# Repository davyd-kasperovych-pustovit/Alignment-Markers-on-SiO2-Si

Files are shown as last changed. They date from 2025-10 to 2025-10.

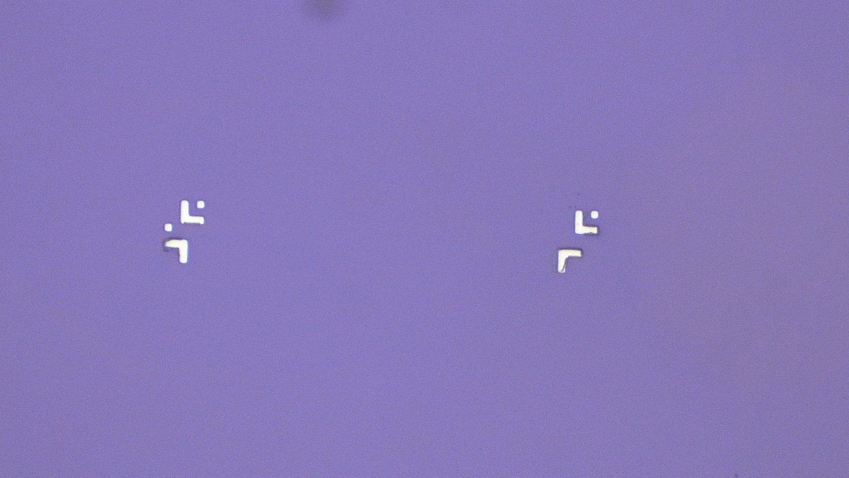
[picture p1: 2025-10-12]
Lift Off Testing/Without Ultrasonic/Lift Off - 2.jpg

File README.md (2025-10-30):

**Alignment Marker Fabrication Process**

**Author:** Davyd Kasperovych-Pustovit

**Affiliation:** Quantum Materials and Devices Lab, Duke University

**Overview**

This repository documents the development and standardization of a photolithography-based alignment marker fabrication process used for device registration and sample alignment in the Quantum Materials and Devices Lab at Duke University.

The project focuses on optimizing process steps to achieve high-fidelity Cr/Au alignment markers on SiO₂/Si substrates with micron-level precision. Through workflow redesign and parameter optimization, total fabrication time was reduced from 12 to 6 hours per 80 markers, while maintaining sub-2 µm feature resolution and consistent pattern reproducibility.

This process is now adopted as the lab’s standard protocol for marker-chip fabrication and serves as the foundation for subsequent device fabrication steps, including graphene and hBN stacking and superconducting device fabrication.

For the final results, see Batches/Batch 4.

**Fabrication Summary**

Substrate: SiO₂/Si wafers (285 nm oxide layer)
Metallization: Cr/Au (5 nm / 50 nm) via thermal evaporation
Resolution: ≤ 2 µm

**Author Notes**

This repository is part of my ongoing undergraduate research in the Quantum Materials and Devices Lab at Duke University.
For questions, collaboration, or feedback, please contact me at:
📧 davydkasperovych@gmail.com

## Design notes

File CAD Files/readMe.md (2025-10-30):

CAD files were adopted from Chun-Chia Chen, Ph.D, and modified by me.
Main change was in the rotation of the left-top marker such that the relative direction can be identified.

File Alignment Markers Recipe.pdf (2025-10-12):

# Procedure for Producing Alignment Markers

# on SiO2/Si Wafers Using Photolithography

Duke University

Quantum Materials and Devices Lab

SMIF Cleanroom Protocol

Prepared by Davyd Kasperovych-Pustovit

Revision 3 - July 30, 2025

## Contents

1 Cleaning the Wafer | 2
2 Spin Coating | 2
3 Photolithography | 3
4 Developing | 3
5 EB Evaporation | 3
6 Photoresist Removal | 4
7 Expected Quality of Alignment Markers | 4
8 Optional: Post Sealing | 5

Revision 3

Davyd Kasperovych-Pustovit

## 1 Cleaning the Wafer

1. At the spin coat hood in the yellow room, turn on two hotplates. Set one to 115°C and the other to 135°C. They will be used later.
2. At the solvent hood with ultrasonic machine, prepare:
(a) Acetone
(b) IPA
(c) DI water
(d) Ensure access to hydrogen gas.
3. Set the ultrasonic machine knob to position 5. If the bath is empty, fill it with IPA.
4. Submerge the wafer in a glass dish filled with acetone.
5. Place the dish with the wafer into the ultrasonic machine. Start the cleaning cycle and run for 5 minutes.
6. While cleaning, prepare a second dish with fresh IPA.
7. After 5 minutes, remove the dish. Lift the wafer while rinsing with IPA, and immediately transfer it to the second dish. Do not let the wafer dry—dried acetone causes stains.
8. Gently agitate the second dish for 60 s.
9. Rinse the wafer under running DI water for 20 s.
10. Dry the wafer thoroughly with nitrogen gas.
11. Transfer wafer to the yellow room for prebaking.
12. Bake the wafer on the 135°C hotplate for 3 minutes. Then let it rest on a clean surface for 2 minutes.

## 2 Spin Coating

1. Set the spin coater program to:
(a) Recipe 0
(b) Step 1: 500 rpm, 5 s – spread
(c) Step 2: 4000 rpm, 30 s – achieve 0.5 µm thickness
(d) Step 3: 0 rpm, 0 s – end
2. Place the wafer on the chuck. Turn on the vacuum and ensure the wafer is secure (change chuck if needed).
3. Using a pipette, dispense enough P20 Primer to evenly coat the wafer.
4. Start the spin cycle. Once complete, turn off the vacuum and transfer the wafer to the 115°C hotplate. Bake for 60 s.
5. Let the wafer cool for 60 s.
6. Repeat the coating steps 2-5 using S1805 PR instead of primer.

## 3 Photolithography

1. Place the wafer at the center of Photo3.
2. Set the wafer thickness to 600 µm.
3. Align the wafer precisely in the x and y directions.
4. Define the dimensions of the write area.
5. Use the build job list function to generate a marker grid.
6. Set the exposure parameters:
(a) Mode: Normal
(b) Resolution: 0.6 µm
(c) Intensity: 60 mJ/cm²
7. Start the exposure process and wait for completion.

Note:
1. The resolution must be finer than your smallest feature (e.g., use 0.6 µm for a 1 µm feature).
2. Refer to the official documentation for detailed instructions.

## 4 Developing

1. Submerge the wafer in MF319 developer for 30 s.
2. Rinse immediately under DI water for 30 s.
3. Dry the wafer using pressurized nitrogen.
4. Inspect the developed features under the microscope using green light. Only use microscope inside the yellow room.
5. If features are unclear, extend development time in MF319 or adjust the exposure intensity on Photo3.

## 5 EB Evaporation

1. Deposit metals in the following order: first Cr, then Au.
2. Use the following target thicknesses:
(a) Cr: 5 nm (0.05 k˚A)
(b) Au: 50 nm (0.5 k˚A)
3. Follow all procedures outlined in the EVAP 2 manual.
4. The full process takes approximately 2.5 hours.

## 6 Photoresist Removal

1. Pour 1165 PR remover into a clean glass dish.
2. Submerge the wafer and soak for 8 hours.
IMPORTANT: After this step, the wafer must remain fully submerged in a solution at all times!
3. After soaking, move the dish to the solvent hood with the ultrasonic machine.
4. Set the ultrasonic machine knob to position 2. Note, higher settings increase the risk of small features detaching.
5. Place the dish with the wafer into the machine and run the cleaning cycle for 3 minutes.
6. While cleaning, prepare a second dish with fresh IPA.
7. After 3 minutes, remove the dish. While rinsing the wafer with IPA, carefully lift it and immediately transfer it to a clean dish.
8. Inspect the wafer under a stereo microscope, checking for any remaining gold dust on the surface.
9. If gold dust is still present, repeat the rinse with IPA and transfer the wafer to a new clean dish. Continue until the wafer is completely free of gold dust.
10. Rinse wafer with DI water.
11. Dry the wafer using pressurized nitrogen.
12. Inspect the wafer to ensure complete photoresist removal.

## 7 Expected Quality of Alignment Markers

1. After Step 4 - Developing in MF319

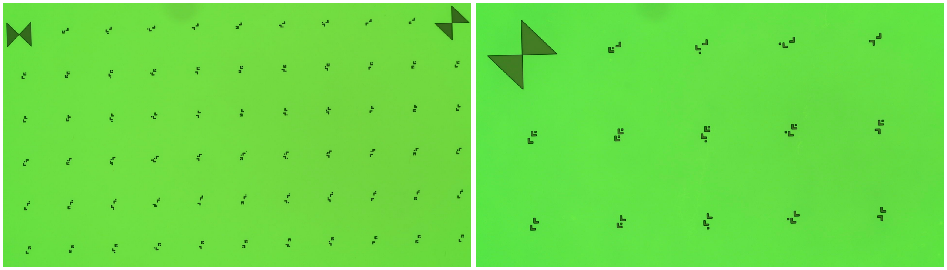
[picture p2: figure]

2. After Step 6 - Photoresist Removal

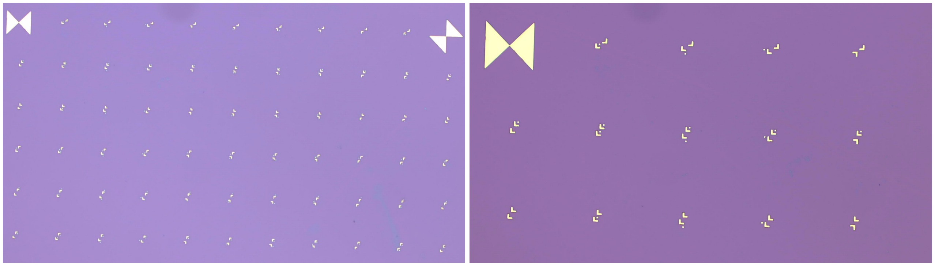
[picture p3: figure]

## 8 Optional: Post Sealing

After complete removal of photoresist (PR), the next step may involve dicing the wafer. This process poses a risk of contaminating wafer features with dust and other particles. To protect the surface, the wafer is coated with a temporary layer of resist that serves as a protective seal.

This layer prevents particle adhesion and can be easily removed after dicing using the standard PR removal procedure.

The procedure is outlined below.
1. At the spin coat hood in the yellow room, set up a hotplate to 180°C. It will be used later.
2. At the solvent hood with ultrasonic machine, prepare:
(a) Acetone
(b) IPA
(c) DI water
(d) Ensure access to hydrogen gas.
3. Set the ultrasonic machine knob to position 2. If the bath is empty, fill it with IPA.
4. Submerge the wafer in a glass dish filled with acetone.
5. Place the dish with the wafer into the ultrasonic machine. Start the cleaning cycle and run for 5 minutes.
6. While cleaning, prepare a second dish with fresh IPA.
7. After 5 minutes, remove the dish. Lift the wafer while rinsing with IPA, and immediately transfer it to the second dish. Do not let the wafer dry—dried acetone causes stains.
8. Gently agitate the second dish for 60 s.
9. Rinse the wafer under running DI water for 20 s.
10. Dry the wafer thoroughly with nitrogen gas.
11. Transfer wafer to the yellow room for prebaking.
12. Bake the wafer on the 180°C hotplate for 2 minutes. Then, let it rest on a clean surface for 2 minutes.
13. Set the spin coater program to:
(a) Recipe 0
(b) Step 1: 500 rpm, 5 s
(c) Step 2: 3000 rpm, 40 s
(d) Step 3: 0 rpm, 0 s
14. Place the wafer on the chuck. Turn on the vacuum and ensure the wafer is secure (change chuck if needed).
15. Using a pipette, dispense enough PMMA 950A4 resist to evenly coat the wafer.
16. Start the spin cycle. Once complete, turn off the vacuum and transfer the wafer to the 180°C hotplate and bake for 2 minutes.
17. Let wafer cool for 2 minutes.
18. Inspect the wafer under the microscope.

## References

- Photo3 Manual: https://smif.pratt.duke.edu/sites/smif.pratt.duke.edu/files/2025/

PHOTO3_SOP_rev-2025-05.pdf (https://smif.pratt.duke.edu/sites/smif.pratt.duke.edu/files/2025/PHOTO3_SOP_rev-2025-05.pdf)

- EB Evaporation: https://smif.pratt.duke.edu/sites/smif.pratt.duke.edu/files/2024/EVAP2%20Operating%20Procedure%2012.pdf (https://smif.pratt.duke.edu/sites/smif.pratt.duke.edu/files/2024/EVAP2%20Operating%20Procedure%2012.pdf)
- Nomarski Microscope Manual: https://smif.pratt.duke.edu/sites/smif.pratt.duke.edu/files/operating/Microscope%20Camera%20Operation_0.pdf (https://smif.pratt.duke.edu/sites/smif.pratt.duke.edu/files/operating/Microscope%20Camera%20Operation_0.pdf)
- PMMA Double Layer Process:

https://smif.pratt.duke.edu/sites/smif.pratt.duke.edu/files/operating/EBL%20Resist%20Processes%206.pdf (https://smif.pratt.duke.edu/sites/smif.pratt.duke.edu/files/operating/EBL%20Resist%20Processes%206.pdf)

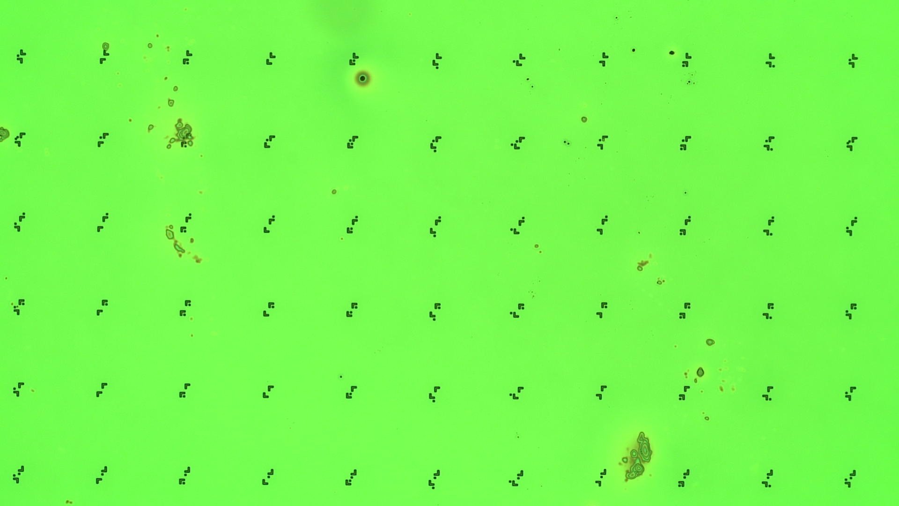
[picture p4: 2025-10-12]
Batches/Batch 3/debris_2.jpg

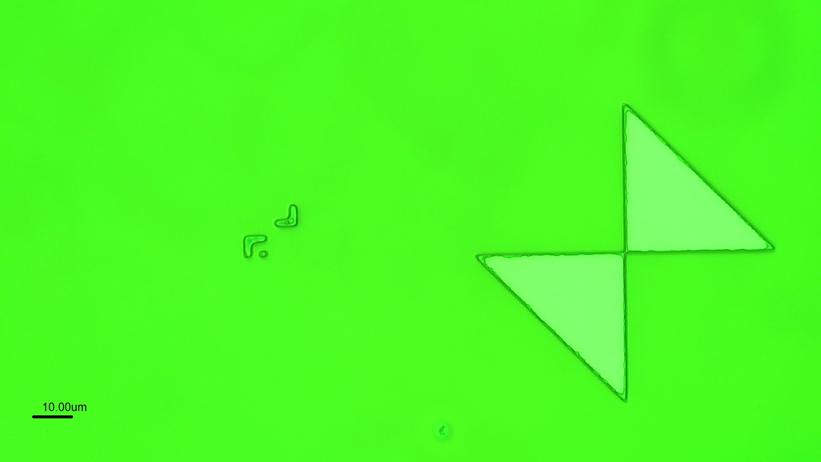
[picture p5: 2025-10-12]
Batches/Batch 1/Picture 1 - 1micron, normal, 1.1x45mJ.jpg.jpg

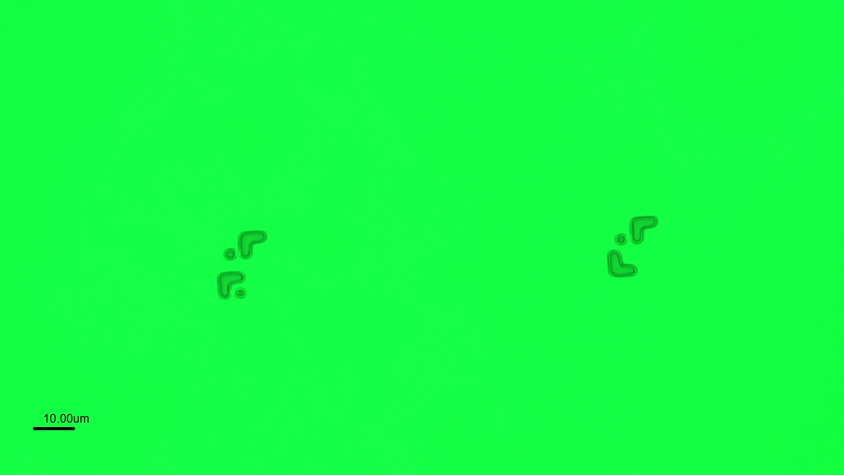
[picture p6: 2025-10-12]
Batches/Batch 2/Picture 2 - 1micron, normal, 1.2x60mJ.jpg

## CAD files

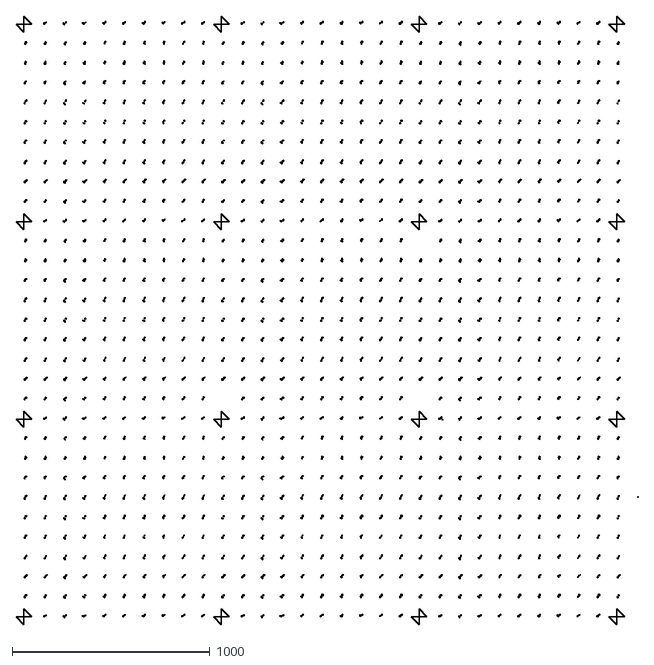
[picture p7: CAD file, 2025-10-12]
CAD Files/3x3_Grid.dxf
3148.0 x 3080.0

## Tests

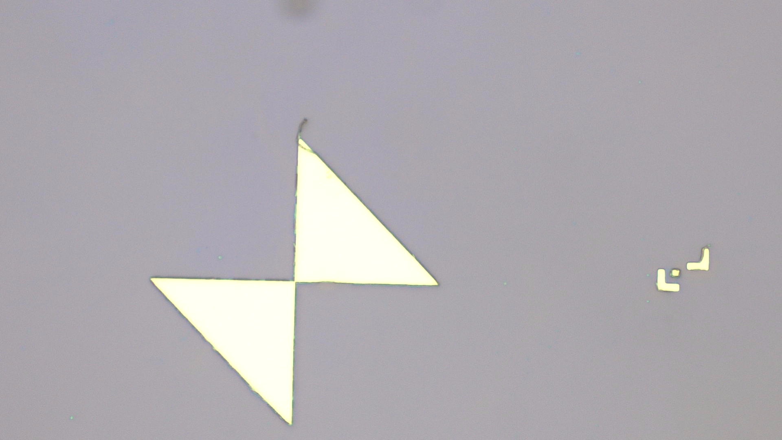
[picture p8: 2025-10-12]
Lift Off Testing/Without Ultrasonic/Lift Off - 1.jpg

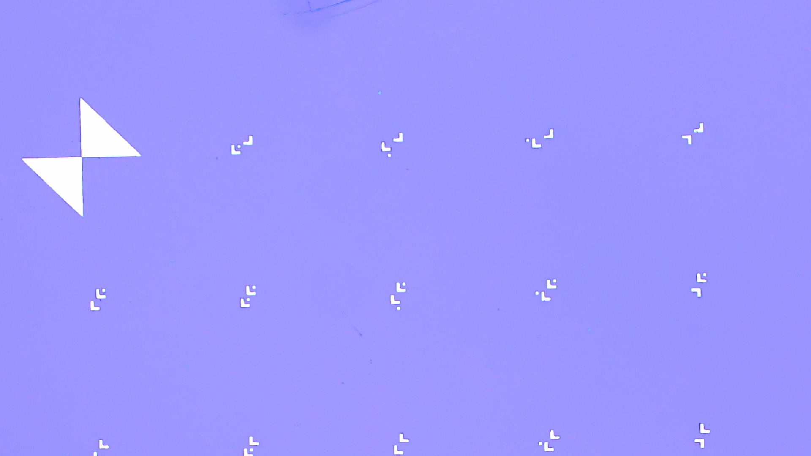
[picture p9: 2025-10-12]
Lift Off Testing/With Ultrasonic/development_1.jpg
